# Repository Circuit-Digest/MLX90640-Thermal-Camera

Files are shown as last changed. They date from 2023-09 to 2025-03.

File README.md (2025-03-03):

# [MLX90640-Thermal-Camera](https://circuitdigest.com/microcontroller-projects/diy-thermal-camera-using-esp32-wrover-module-and-mlx90640-sensor) 

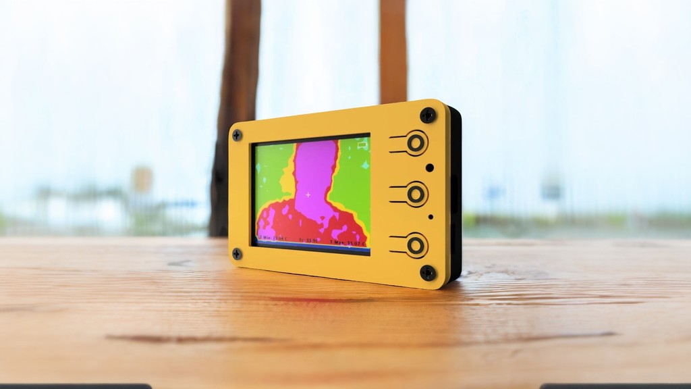
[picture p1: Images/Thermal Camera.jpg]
image_tooltip

<br>

<div style="display: flex; flex-wrap: nowrap;">
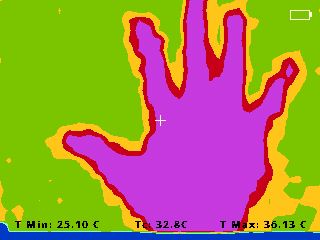
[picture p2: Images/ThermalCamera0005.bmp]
image_tooltip
    
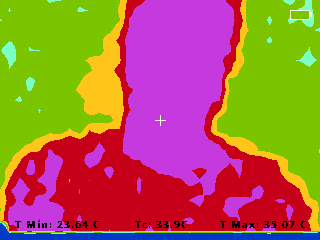
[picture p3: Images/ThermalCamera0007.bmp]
image_tooltip
    
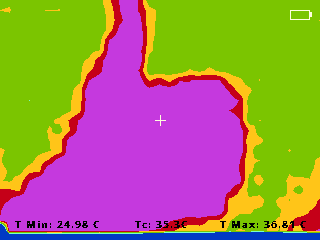
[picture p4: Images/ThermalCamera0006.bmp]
image_tooltip
    
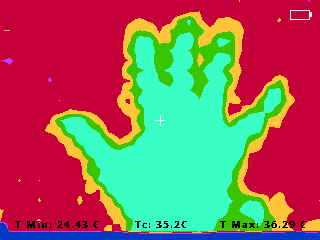
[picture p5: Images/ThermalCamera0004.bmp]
image_tooltip
    
</div>
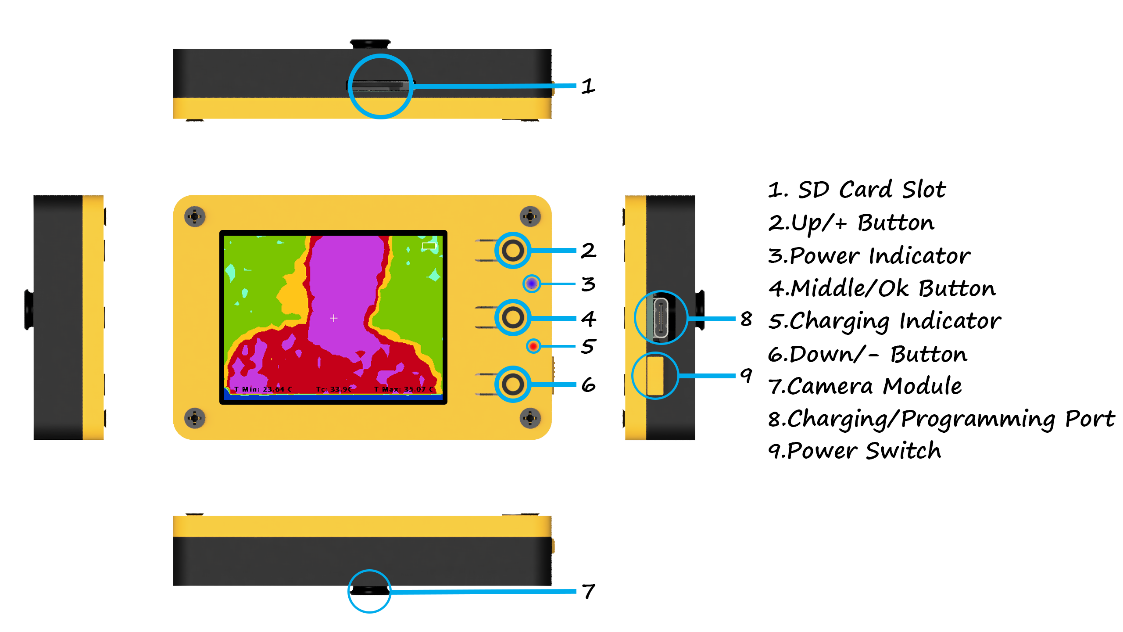
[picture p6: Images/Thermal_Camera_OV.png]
image_tooltip

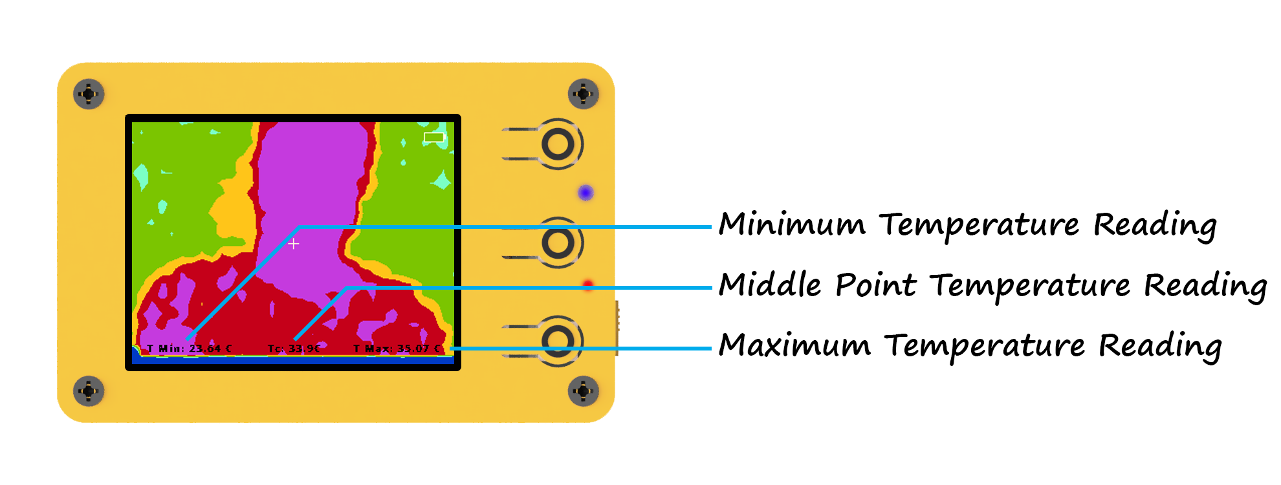
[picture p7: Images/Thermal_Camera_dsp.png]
image_tooltip
<br>
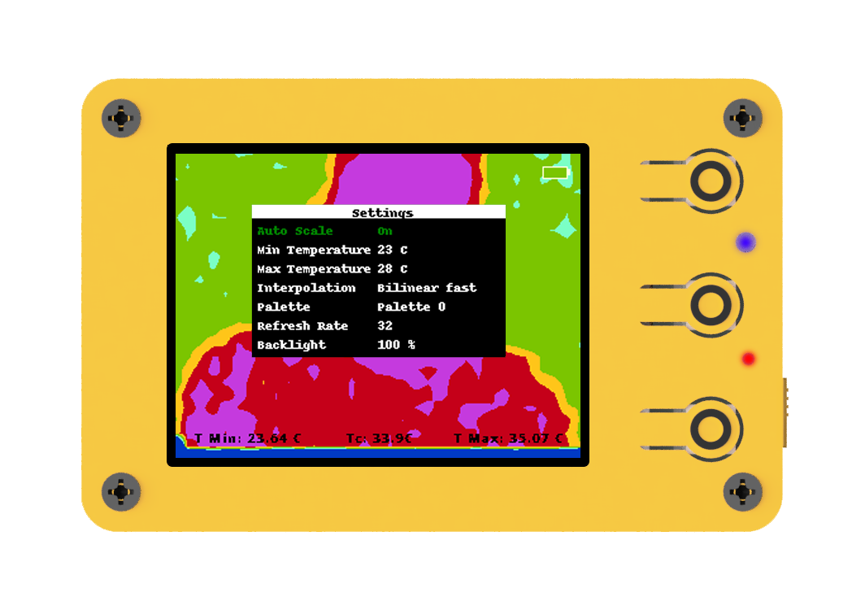
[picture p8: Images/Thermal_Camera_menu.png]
image_tooltip
<br>
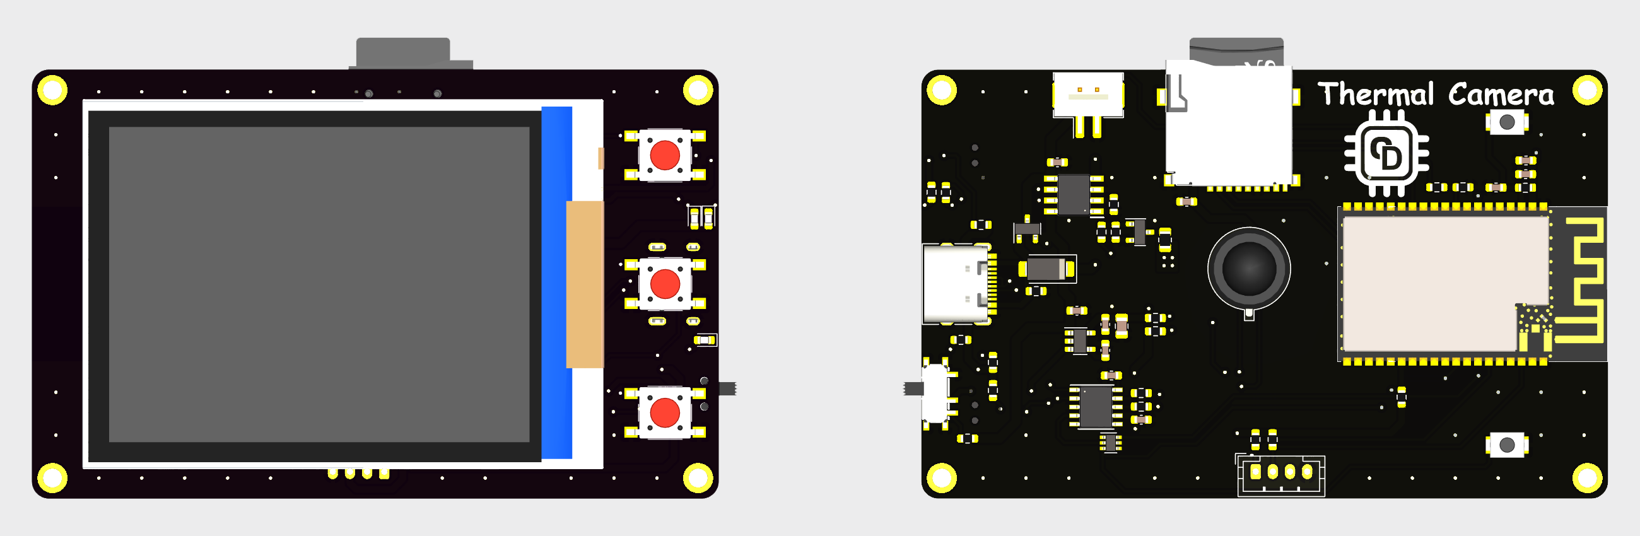
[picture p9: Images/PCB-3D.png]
image_tooltip
<br>
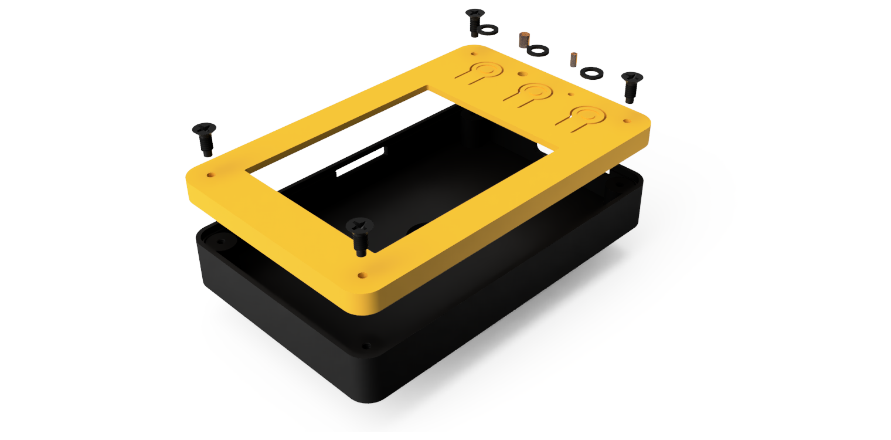
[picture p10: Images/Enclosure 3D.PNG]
image_tooltip
<br>
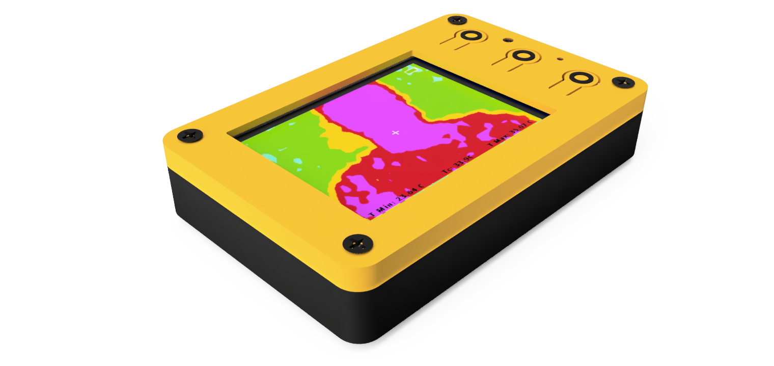
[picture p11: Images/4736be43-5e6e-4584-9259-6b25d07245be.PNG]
image_tooltip
<br>

<br>

Thermal Cameras are widely used in a wide range of industrial applications such as thermal performance monitoring, detecting temperature anomalies, thermal bench marking and many more. We even use thermal imaging even for defense and military applications. The most common application that we may come across, is might be the electronics repair industry. In repair industry the thermal cameras are a very important tool which can make the hardware debugging much easier especially where there are shorted parts are involved. The main concern regarding such thermal imager is that they are pretty expensive. 
So, in this project we are going to find some solution for that by making a DIY thermal imager using much cheaper available components. The cheaper thermal imaging sensors we have considered are the AMG8833 from Panasonic and MLX90640 and MLX90641 from Melexis. Even though the AMG8833 is the cheapest of them all it only has a resolution o f 8x8, while MLX90640 offers a resolution of 32x24 and MLX90641 offers a resolution of 16x12. Since the MLX90640 offers the best resolution in the price range we choose it for our DIY thermal camera.

<br>
[Note: As this projects are very simple we are only providing the code, schemaitic, and a few essential images if you want to get the images or code explanations do check out the Circuit Digest website.
<br>
<br>

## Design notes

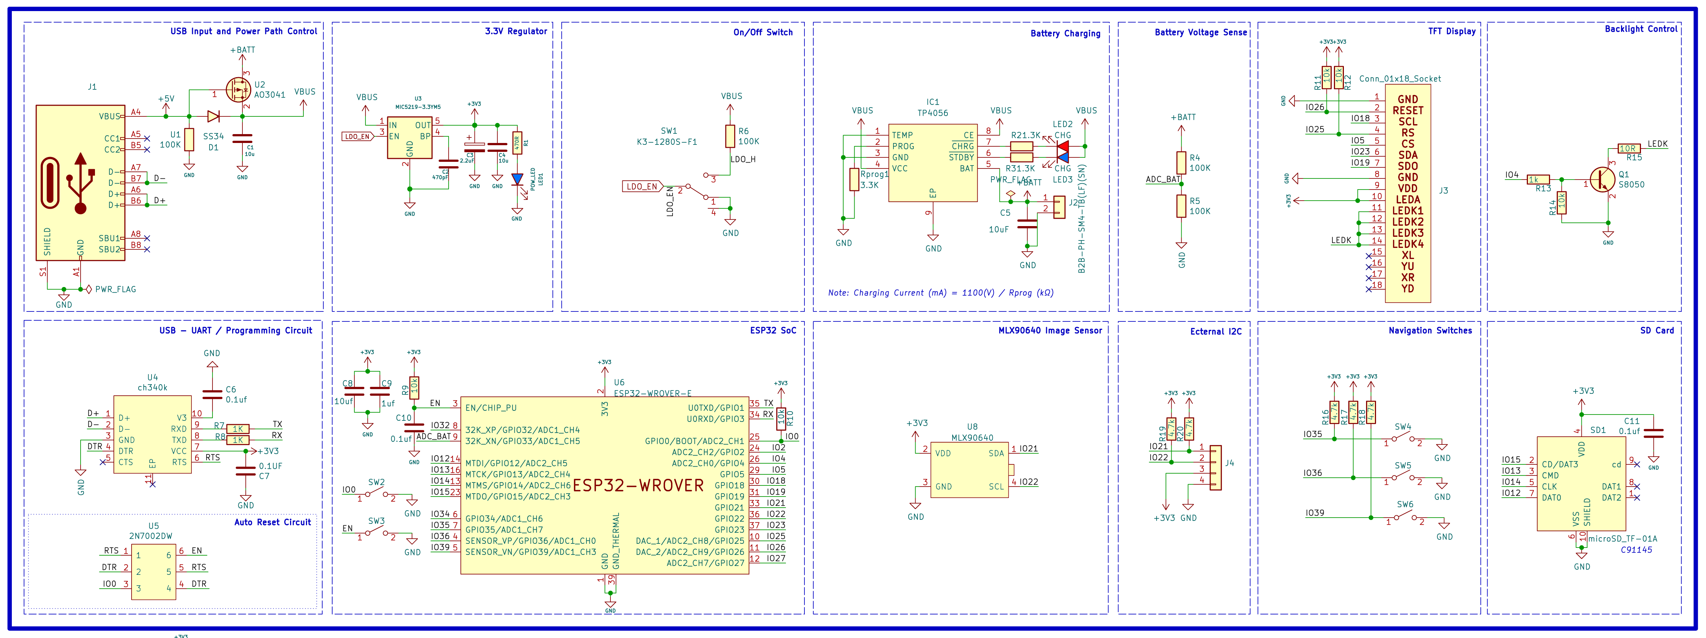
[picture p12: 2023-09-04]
Images/Thermal_Camera Schematics.png

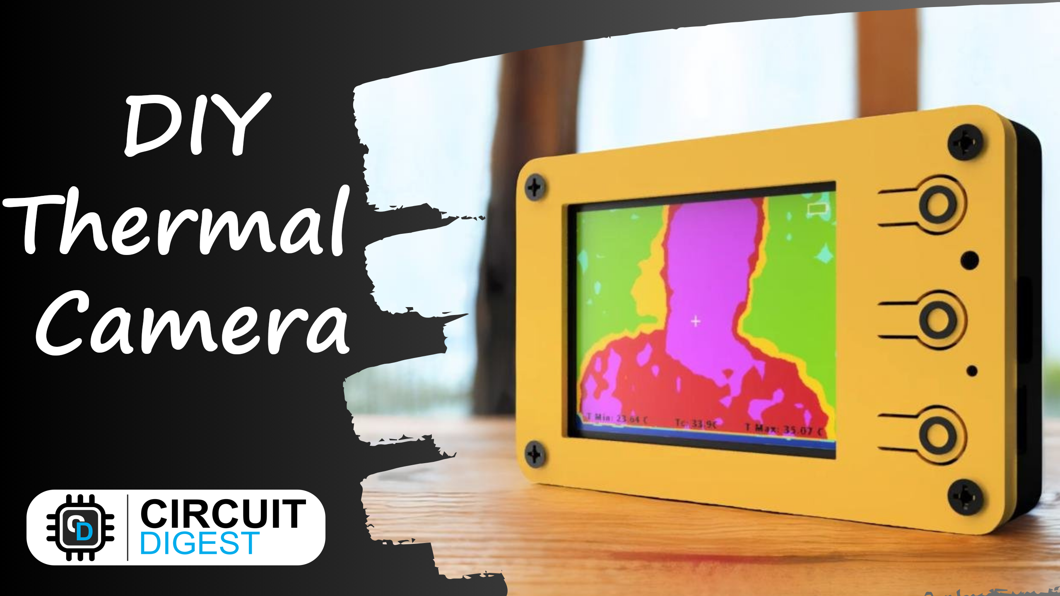
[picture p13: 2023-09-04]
Images/Title Image.png

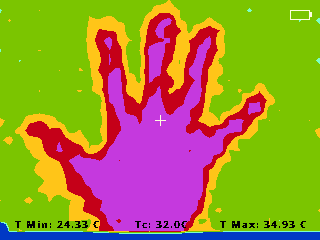
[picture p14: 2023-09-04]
Images/ThermalCamera0014.bmp

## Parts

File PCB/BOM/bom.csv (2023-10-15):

Designator | Footprint | Quantity | Value | LCSC Part #
C1, C4 | 603 | 2 | 10u
C10, C11, C6, C7 | 603 | 4 | 0.1uf
C2 | 603 | 1 | 470pF
C3 | 805 | 1 | 2.2uF
C5, C8 | 603 | 2 | 10uF
C9 | 603 | 1 | 1uf
D1 | D_SMA | 1 | SS34
H1, H2, H3, H4 | MountingHole_2.2mm_M2_ISO7380_Pad | 4 | MountingHole
IC1 | SOIC127P600X175-9N | 1 | TP4056
J1 | USB_C_Receptacle_HRO_TYPE-C-31-M-12 | 1 | USB_C_Receptacle_USB2.0
J2 | JST_PH_B2B-PH-SM4-TB_1x02-1MP_P2.00mm_Vertical | 1 | B2B-PH-SM4-TB(LF)(SN)
J3 | 24LCDILI9341 | 1 | Conn_01x18_Socket
J4 | JST_PH_B4B-PH-K_1x04_P2.00mm_Vertical | 1 | Stemma
LED1 | 603 | 1 | POW_LED
LED2, LED3 | 603 | 2 | CHG
Q1 | SOT-23 | 1 | S8050
R1 | 603 | 1 | 470R
R10, R11, R12, R14, R9 | 603 | 5 | 10k
R13, R7, R8 | 603 | 3 | 1k
R15 | 805 | 1 | 10R
R16, R17, R18, R19, R20 | 603 | 5 | 4.7k
R2, R3 | 603 | 2 | 1.3K
R4, R5, R6, U1 | 603 | 4 | 100K
Rprog1 | 603 | 1 | 3.3K
SD1 | microSD_TF-01A-C91145 | 1 | microSD_TF-01A
SW1 | slide switch spdt | 1 | K3-1280S-F1
SW2_4, SW2_3, SW2_2 | PTS645SL43SMTR92LFS | 3 | SW_SPST
SW2, SW3, SW4, SW5, SW6 | Tactile 3x4x2mm TS-A010 | 5 | TS-1088R-02526
U2 | SOT-23 | 1 | AO3401
U3 | SOT-23-5 | 1 | MIC5219-3.3YM5
U4 | ESSOP-10_3.9x4.9mm_P1.00mm | 1 | ch340k
U5 | SOT-363_SC-70-6 | 1 | 2N7002DW
U6 | ESP32-WROVER-E | 1 | ESP32-WROVER-E
U7 | ESP32-WROOM-32E | 1 | ESP32-WROOM-E
U8 | MLX90640 | 1 | MLX90640

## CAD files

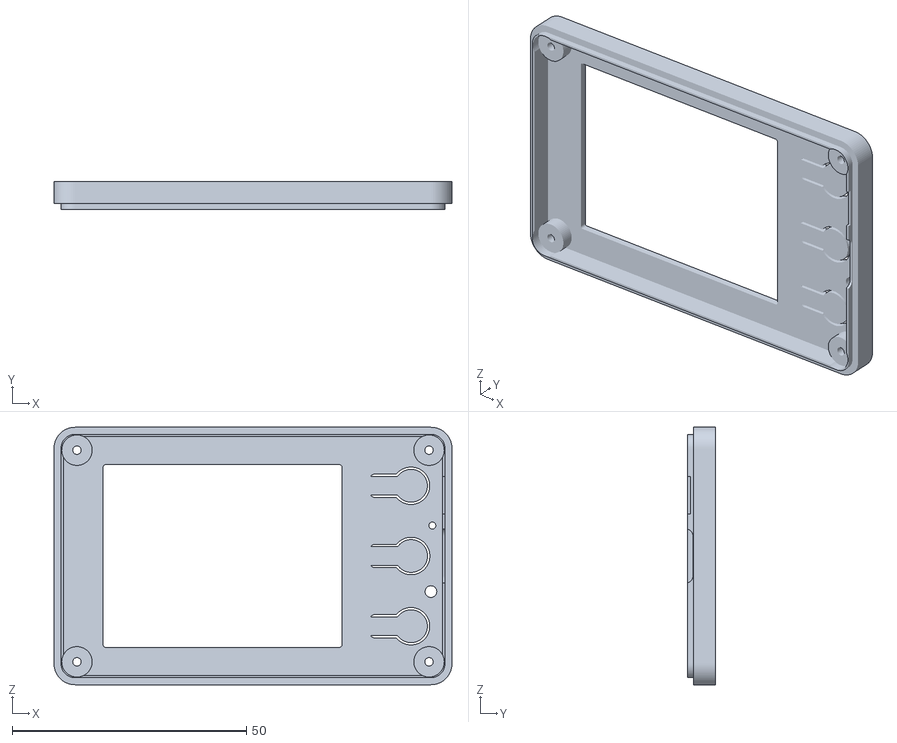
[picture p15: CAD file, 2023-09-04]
STL/top.stl
85.0 x 6.05 x 55.0

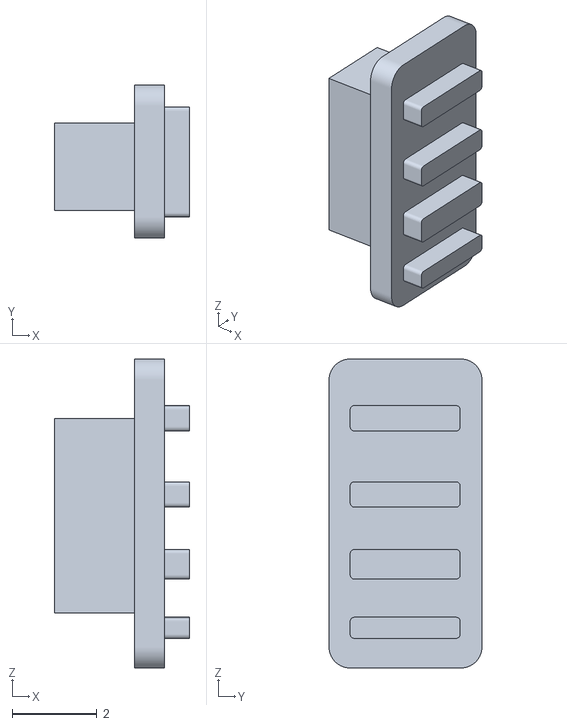
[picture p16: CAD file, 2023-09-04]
STL/slide.stl
3.20 x 3.61 x 7.30

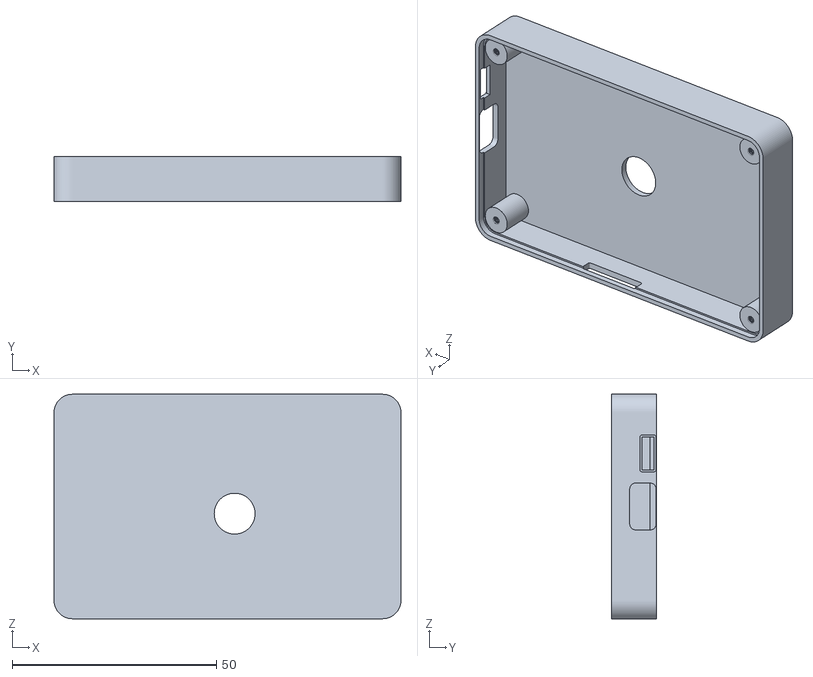
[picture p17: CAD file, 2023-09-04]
STL/Btm.stl
85.0 x 11.1 x 55.0

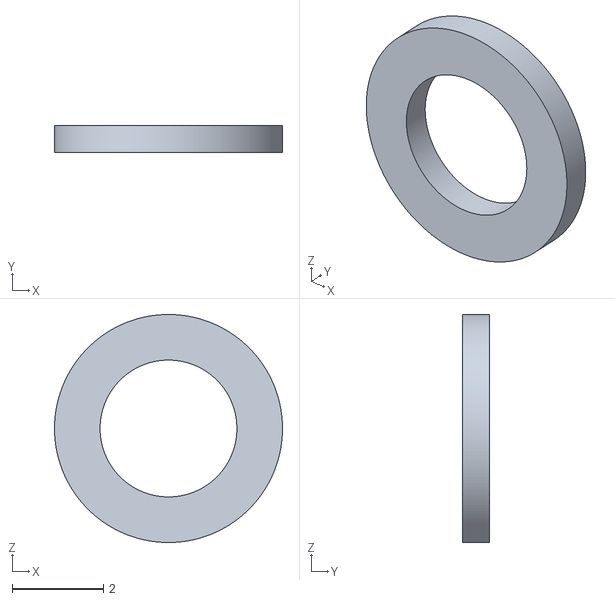
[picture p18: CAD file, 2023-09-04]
STL/button.stl
5.00 x 0.6 x 5.00

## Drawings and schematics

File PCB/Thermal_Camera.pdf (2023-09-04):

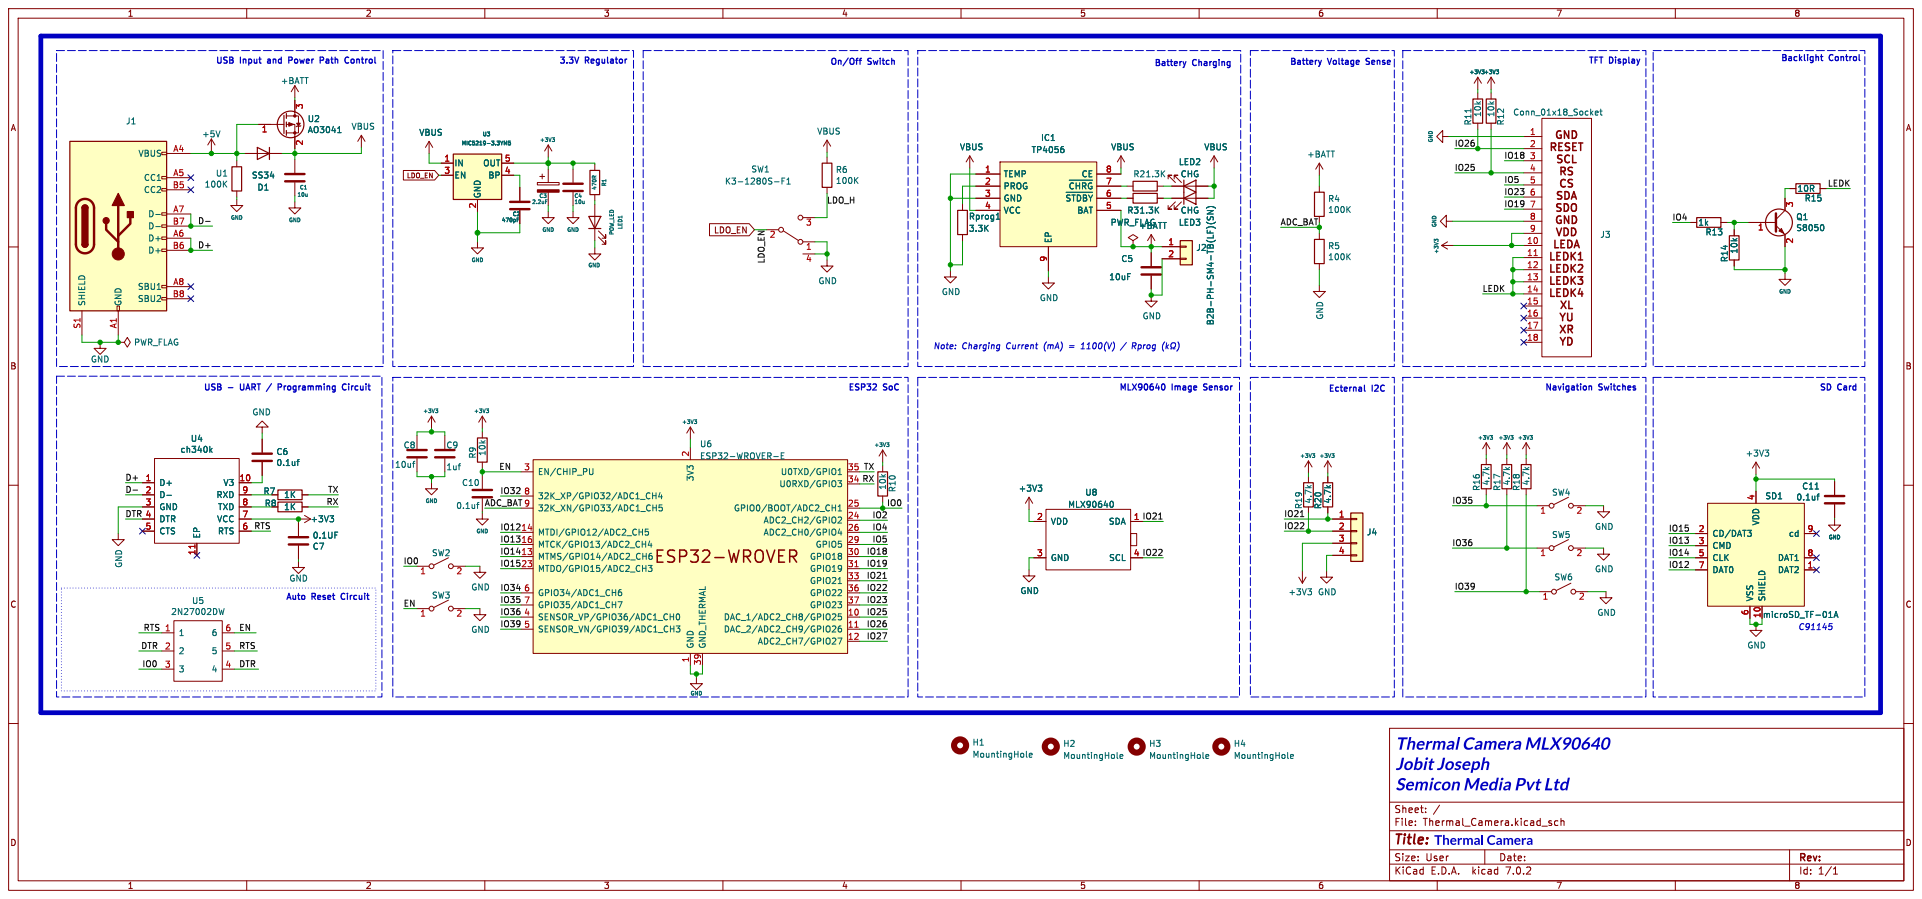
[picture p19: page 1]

TFT Display Note: Charging Current (mA) = 1100(V) / Rprog þÿ(k©)

2 3 U2AO3041 SDA 1 VDD 2 GND 3 SCL 4 U8 MLX90640 C6

LED3 CHG

Id: 1/1 Title: File: Thermal_Camera.kicad_sch Sheet: / +3V3

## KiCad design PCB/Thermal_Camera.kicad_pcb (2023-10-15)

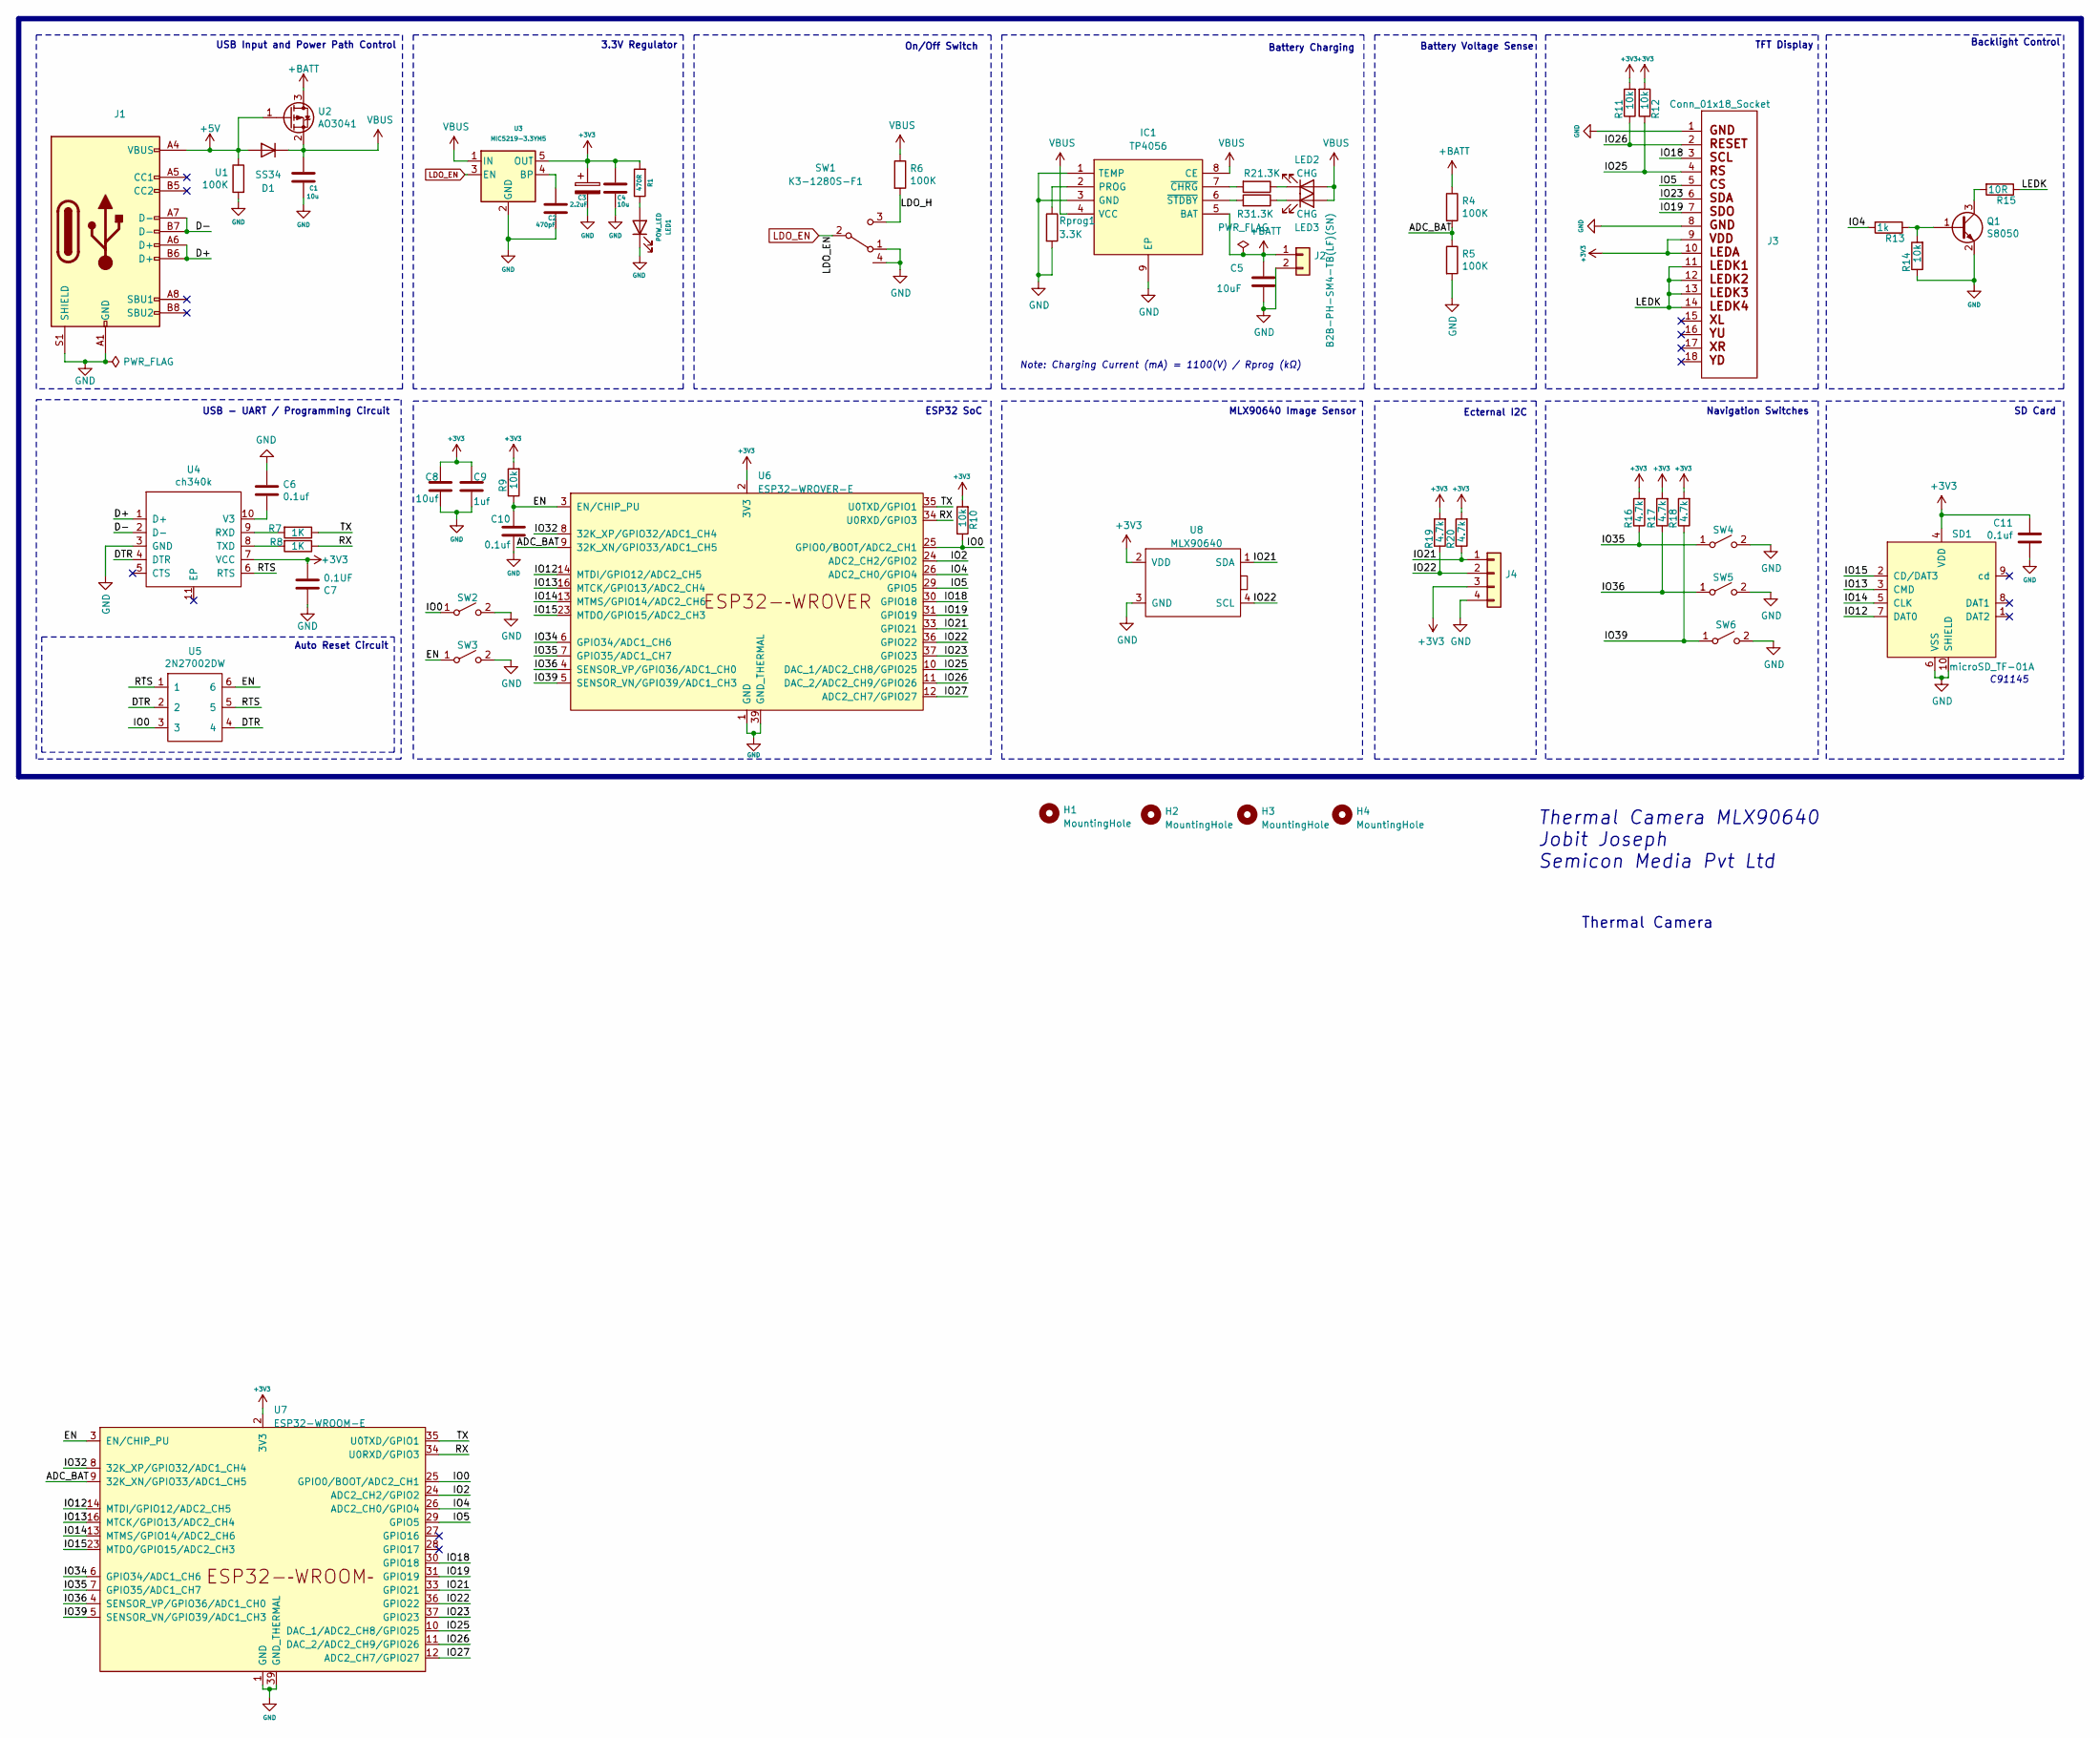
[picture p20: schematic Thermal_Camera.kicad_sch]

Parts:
C1, C4: 10u; C_0603_1608Metric
C2: 470pF; C_0603_1608Metric
C3: 2.2uF; C_0805_2012Metric
C5: 10uF; C_0603_1608Metric
C6, C10, C11: 0.1uf; C_0603_1608Metric
C7: 0.1UF; C_0603_1608Metric
C8: 10uf; C_0603_1608Metric
C9: 1uf; C_0603_1608Metric
D1: SS34; D_SMA
H1, H2, H3, H4: MountingHole; MountingHole_2.2mm_M2_ISO7380_Pad
IC1: TP4056; SOIC127P600X175-9N; Manufacturer_Part_Number TP4056-42-ESOP8
J1: USB_C_Receptacle_USB2.0; USB_C_Receptacle_HRO_TYPE-C-31-M-12
J2: B2B-PH-SM4-TB(LF)(SN); JST_PH_B2B-PH-SM4-TB_1x02-1MP_P2.00mm_Vertical
J3: Conn_01x18_Socket; 24LCDILI9341
J4: Stemma; JST_PH_B4B-PH-K_1x04_P2.00mm_Vertical
LED1: POW_LED; LED_0603_1608Metric
LED2, LED3: CHG; LED_0603_1608Metric
Q1: S8050; SOT-23
R1: 470R; R_0603_1608Metric
R2, R3: 1.3K; R_0603_1608Metric
R4, R5, R6: 100K; R_0603_1608Metric
R7, R8: 1K; R_0603_1608Metric
R9, R10, R11, R12, R14: 10k; R_0603_1608Metric
R13: 1k; R_0603_1608Metric
R15: 10R; R_0805_2012Metric
R16, R17, R18, R19, R20: 4.7k; R_0603_1608Metric
Rprog1: 3.3K; R_0603_1608Metric
SD1: microSD_TF-01A; microSD_TF-01A-C91145
SW1: K3-1280S-F1; slide switch spdt
SW2, SW3, SW4, SW5, SW6: TS-1088R-02526; Tactile 3x4x2mm TS-A010
U1: 100K; R_0603_1608Metric
U2: AO3041; SOT-23
U3: MIC5219-3.3YM5; SOT-23-5
U4: ch340k; ESSOP-10_3.9x4.9mm_P1.00mm
U5: 2N27002DW; SOT-363_SC-70-6
U6: ESP32-WROVER-E
U7: ESP32-WROOM-E; ESP32-WROOM-32E
U8: MLX90640

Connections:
+3V3: C3.1, C4.1, C7.2, C8.1, C9.1, C11.1, J3.9 (VDD), J3.10 (LEDA), J4.3, R1.2, R9.2, R10.2, R11.2, R12.2, R16.2, R17.2, R18.2, R19.2, R20.2, SD1.4 (VDD), U3.5 (OUT), U4.7 (VCC), U6.2 (3V3), U7.2 (3V3), U8.2 (VDD)
+5V: D1.2 (A), J1.A4 (VBUS), J1.A9 (VBUS), J1.B4 (VBUS), J1.B9 (VBUS), U1.1, U2.1 (G)
+BATT: C5.1, IC1.5 (BAT), J2.1, R4.1, U2.3 (D)
/ADC_BAT: R4.2, R5.1, U6.9 (32K_XN/GPIO33/ADC1_CH5), U7.9 (32K_XN/GPIO33/ADC1_CH5)
/D+: J1.A6 (D+), J1.B6 (D+), U4.1 (D+)
/D-: J1.A7 (D-), J1.B7 (D-), U4.2 (D-)
/DTR: U4.4 (DTR), U5.2, U5.4
/EN: C10.1, R9.1, SW3.1 (A), U5.6, U6.3 (EN/CHIP_PU), U7.3 (EN/CHIP_PU)
/IO2: U6.24 (ADC2_CH2/GPIO2), U7.24 (ADC2_CH2/GPIO2)
/IO4: R13.2, U6.26 (ADC2_CH0/GPIO4), U7.26 (ADC2_CH0/GPIO4)
/IO5: J3.5 (CS), U6.29 (GPIO5), U7.29 (GPIO5)
/IO12: SD1.7 (DAT0), U6.14 (MTDI/GPIO12/ADC2_CH5), U7.14 (MTDI/GPIO12/ADC2_CH5)
/IO13: SD1.3 (CMD), U6.16 (MTCK/GPIO13/ADC2_CH4), U7.16 (MTCK/GPIO13/ADC2_CH4)
/IO14: SD1.5 (CLK), U6.13 (MTMS/GPIO14/ADC2_CH6), U7.13 (MTMS/GPIO14/ADC2_CH6)
/IO15: SD1.2 (CD/DAT3), U6.23 (MTDO/GPIO15/ADC2_CH3), U7.23 (MTDO/GPIO15/ADC2_CH3)
/IO18: J3.3 (SCL), U6.30 (GPIO18), U7.30 (GPIO18)
/IO19: J3.7 (SDO), U6.31 (GPIO19), U7.31 (GPIO19)
/IO21: J4.1, R20.1, U6.33 (GPIO21), U7.33 (GPIO21), U8.1 (SDA)
/IO22: J4.2, R19.1, U6.36 (GPIO22), U7.36 (GPIO22), U8.4 (SCL)
/IO23: J3.6 (SDA), U6.37 (GPIO23), U7.37 (GPIO23)
/IO25: J3.4 (RS), R12.1, U6.10 (DAC_1/ADC2_CH8/GPIO25), U7.10 (DAC_1/ADC2_CH8/GPIO25)
/IO26: J3.2 (RESET), R11.1, U6.11 (DAC_2/ADC2_CH9/GPIO26), U7.11 (DAC_2/ADC2_CH9/GPIO26)
/IO27: U6.12 (ADC2_CH7/GPIO27), U7.12 (ADC2_CH7/GPIO27)
/IO32: U6.8 (32K_XP/GPIO32/ADC1_CH4), U7.8 (32K_XP/GPIO32/ADC1_CH4)
/IO34: U6.6 (GPIO34/ADC1_CH6), U7.6 (GPIO34/ADC1_CH6)
/IO36: R17.1, SW5.1 (A), U6.4 (SENSOR_VP/GPIO36/ADC1_CH0), U7.4 (SENSOR_VP/GPIO36/ADC1_CH0); also elsewhere on the board
/IO39: R18.1, SW6.1 (A), U6.5 (SENSOR_VN/GPIO39/ADC1_CH3), U7.5 (SENSOR_VN/GPIO39/ADC1_CH3); also elsewhere on the board
/LDO_H: R6.2, SW1.3 (C)
/LEDK: J3.11 (LEDK1), J3.12 (LEDK2), J3.13 (LEDK3), J3.14 (LEDK4), R15.1
/RTS: U4.6 (RTS), U5.1, U5.5
/RX: R8.1, U6.34 (U0RXD/GPIO3), U7.34 (U0RXD/GPIO3)
/TX: R7.1, U6.35 (U0TXD/GPIO1), U7.35 (U0TXD/GPIO1)
LDO_EN: SW1.2 (B), U3.3 (EN)
unnamed: IC1.2 (PROG), Rprog1.1
unnamed: IC1.7 (~CHRG), R2.2
unnamed: IC1.6 (~STDBY), R3.2
unnamed: LED1.2 (A), R1.1
unnamed: LED2.1 (K), R2.1
unnamed: LED3.1 (K), R3.1
unnamed: Q1.3 (C), R15.2
unnamed: Q1.1 (E), R13.1, R14.2
unnamed: C2.1, U3.4 (BP)
unnamed: R7.2, U4.9 (RXD)
unnamed: R8.2, U4.8 (TXD)
unnamed: C6.2, U4.10 (V3)
VBUS: C1.1, D1.1 (K), IC1.4 (VCC), IC1.8 (CE), LED2.2 (A), LED3.2 (A), R6.1, U2.2 (S), U3.1 (IN)

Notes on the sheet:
Auto Reset Circuit
Battery Charging
Navigation Switches
Thermal Camera MLX90640 Jobit Joseph Semicon Media Pvt Ltd
TFT Display
MLX90640 Image Sensor
On/Off Switch
Ecternal I2C
Note: Charging Current (mA) = 1100(V) / Rprog (kΩ)
ESP32 SoC
C91145
Backlight Control
SD Card
3.3V Regulator
Battery Voltage Sense
USB Input and Power Path Control
Thermal Camera
USB - UART / Programming Circuit

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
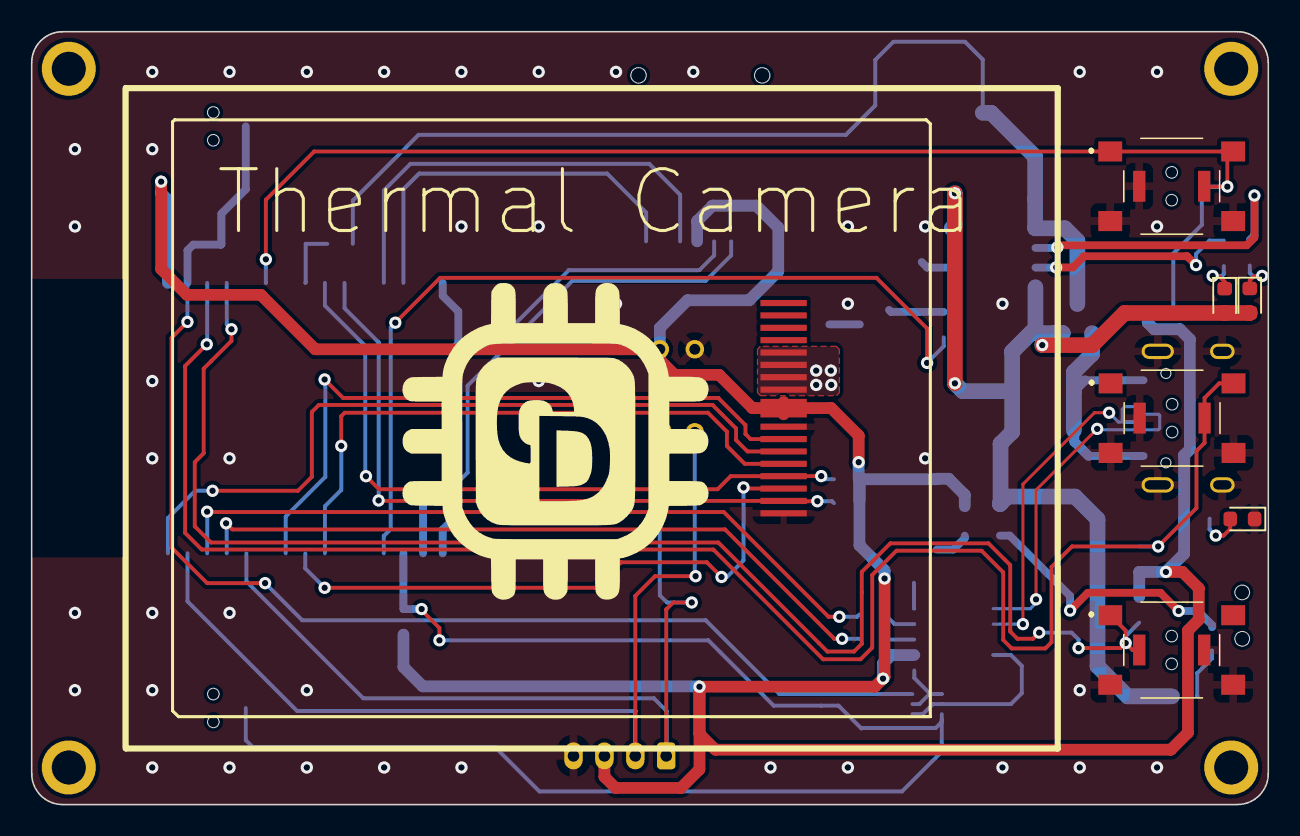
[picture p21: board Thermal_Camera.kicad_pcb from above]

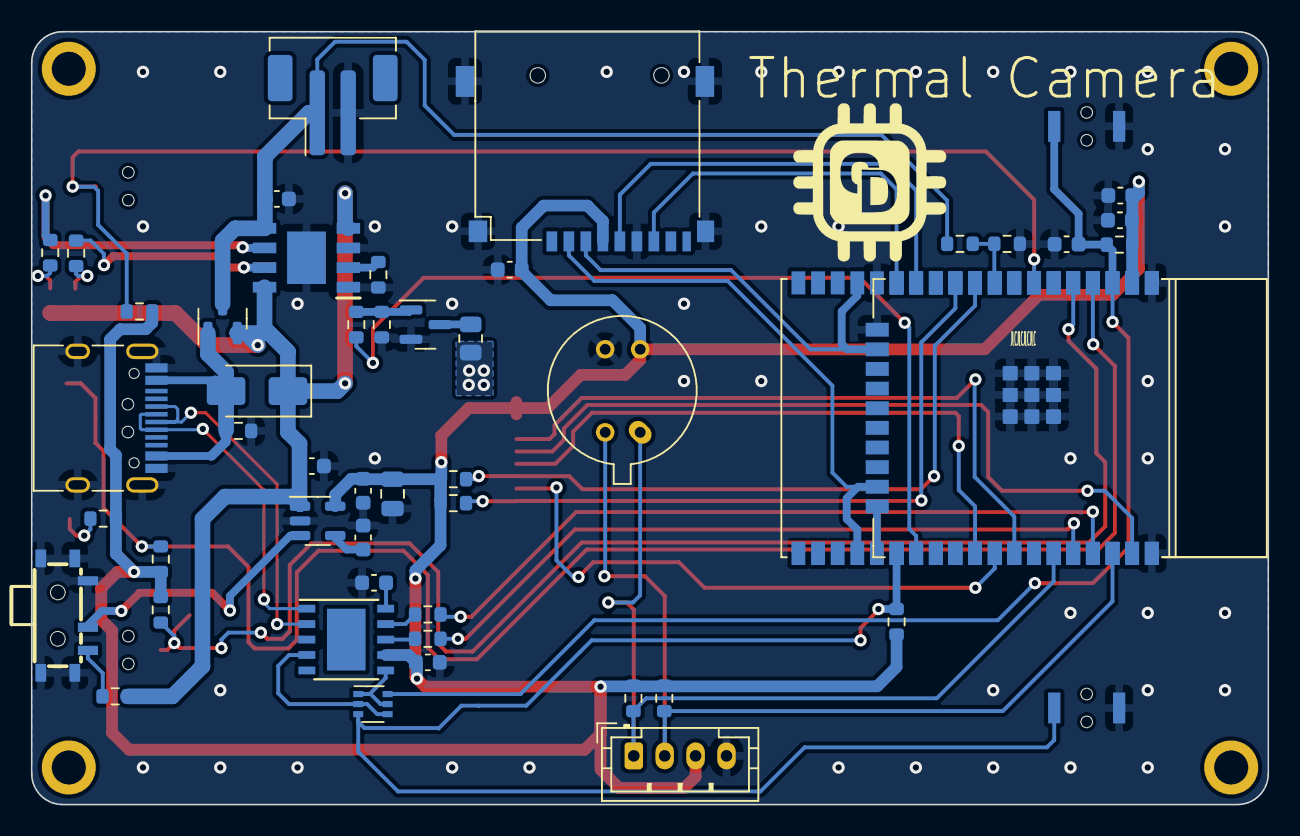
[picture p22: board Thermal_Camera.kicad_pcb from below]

Board: 2 copper layers, 80.0 x 50.0 mm, 64 parts (50 on the bottom side), 49 nets.

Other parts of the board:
SW2#2, SW2#3: SW_SPST; PTS645SL43SMTR92LFS
SW2#4: TS-1088R-02526; Tactile 3x4x2mm TS-A010

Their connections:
/IO36: SW2#2.2 (A); also elsewhere on the board
/IO39: SW2#3.1 (A); also elsewhere on the board

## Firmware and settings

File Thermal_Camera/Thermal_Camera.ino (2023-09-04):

/*
 * Project Name: MLX90640 Thermal Camera
 * Project Brief: Firmware for Thermal camera built around ESP32 and MLX90640
 * Author: Jobit Joseph
 * Copyright © Jobit Joseph
 * Copyright © Semicon Media Pvt Ltd
 * Copyright © Circuitdigest.com
 * 
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
 */
#include <Preferences.h>
#include <Wire.h>
#include <SPI.h>
#include <SD.h>
#include "FS.h"
#include <Adafruit_MLX90640.h>
#include <TFT_eSPI.h>
#include <AnimatedGIF.h>
#include <Fonts/GFXFF/gfxfont.h>  //Include a library of Fonts
#include "Open_Sans_ExtraBold_10.h"
#include "BootAnimation.h"
#include "success.h"
#include "Error.h"
SPIClass spiSD(HSPI);
#define SD_CS 15
//#define USE_DMA
#define NORMAL_SPEED
#define TFT_WIDTH 320
#define TFT_HEIGHT 240
#define BUFFER_SIZE 320
uint16_t usTemp[BUFFER_SIZE];
#define VBAT_PIN 33
#define BATTV_MAX 4.2  // maximum voltage of battery
#define BATTV_MIN 3.2  // what we regard as an empty battery
#define GIF_IMAGE BootAnimationIMG
#define SGIF_IMAGE success_GIF
#define EGIF_IMAGE Error_GIF
bool dmaBuf = 0;
Adafruit_MLX90640 mlx;
Preferences preferences;
AnimatedGIF gif;
TFT_eSPI tft = TFT_eSPI();
File bmpFile;
float frame[32 * 24];
float batv;
const int upButton = 35;
const int middleButton = 36;
const int downButton = 39;
const int backlightPin = 4;
int interpolationMode = 0;
int AutoScale = 0;
volatile bool MenuChange = false;
volatile bool _upShort = false;
volatile bool _downShort = false;
volatile bool middleShort = false;
volatile bool middlePressed = false;
unsigned long middlePressStartTime = 0;
int Menu = 0, Menuitem = 0;
int BLPWM = 0;
int RefreshRate = 0;
float MinT, MaxT;
String menuItems[7] = { "Auto Scale    : ", "Min Temp      : ", "Max Temp      : ", "Interpolation : ", "Palette       : ", "Refresh Rate  : ", "BackLight     : " };
String ASindex[2] = { "Off", "On" };
String IPindex[6] = { "Nearest Neighbor", "Average", "Bilinear", "Bilinear Fast", "Triangle" };
String RRindex[4] = { "4 Hz", "8 Hz", "16 Hz", "32 Hz" };
float xRatios[320];
float yRatios[240];
float xOppositeRatios[320];
float yOppositeRatios[240];
#define PALETTE_COUNT 10
uint16_t colorPalettes[PALETTE_COUNT][6] = {
  { TFT_BLUE, TFT_CYAN, TFT_GREEN, TFT_YELLOW, TFT_RED, TFT_MAGENTA },
  { TFT_BLACK, TFT_DARKGREY, TFT_LIGHTGREY, TFT_WHITE, TFT_ORANGE, TFT_PINK },
  { TFT_NAVY, TFT_OLIVE, TFT_DARKGREEN, TFT_DARKCYAN, TFT_MAROON, TFT_PURPLE },
  { TFT_BLUE, TFT_GREEN, TFT_DARKGREEN, TFT_ORANGE, TFT_MAROON, TFT_RED },
  { TFT_NAVY, TFT_DARKGREEN, TFT_GREEN, TFT_YELLOW, TFT_ORANGE, TFT_RED },
  { TFT_CYAN, TFT_BLUE, TFT_MAGENTA, TFT_YELLOW, TFT_GREEN, TFT_RED },
  { TFT_WHITE, TFT_ORANGE, TFT_RED, TFT_BLUE, TFT_GREEN, TFT_BLACK },
  { TFT_PURPLE, TFT_MAGENTA, TFT_RED, TFT_ORANGE, TFT_YELLOW, TFT_GREEN },
  { TFT_YELLOW, TFT_PINK, TFT_WHITE, TFT_BLUE, TFT_DARKCYAN, TFT_DARKGREEN },
  { TFT_RED, TFT_YELLOW, TFT_GREEN, TFT_CYAN, TFT_BLUE, TFT_MAGENTA }
};
int paletteIndex = 0;

float tempMin = 20.0;  // Minimum temperature
float tempMax = 32.0;  // Maximum temperature

TFT_eSprite sprite = TFT_eSprite(&tft);


void IRAM_ATTR upButton_ISR() {
  static unsigned long last_interrupt_time = 0;
  unsigned long interrupt_time = millis();

  if (interrupt_time - last_interrupt_time > 200) {  // simple debounce
    _upShort = true;
  }
  last_interrupt_time = interrupt_time;
}

void IRAM_ATTR downButton_ISR() {
  static unsigned long last_interrupt_time = 0;
  unsigned long interrupt_time = millis();

  if (interrupt_time - last_interrupt_time > 200) {  // simple debounce
    _downShort = true;
  }
  last_interrupt_time = interrupt_time;
}

void IRAM_ATTR middleButton_ISR() {
  if (digitalRead(middleButton) == LOW) {
    // Button press event
    if (!middlePressed) {  // If button was not already being pressed
      middlePressed = true;
      middlePressStartTime = millis();  // Save the start time of button press
    }
  } else {
    // Button release event
    if (middlePressed) {                             // If the button was being pressed
      if (millis() - middlePressStartTime < 1000) {  // If the button was pressed for less than 1 second
        middleShort = true;
      }
      middlePressed = false;
      middlePressStartTime = 0;  // Reset the start time of button press
    }
  }
}



void MLXInit() {

  Wire.begin();
  Wire.setClock(1000000);
  if (!mlx.begin()) {
    Serial.println("Failed to initialize MLX90640!");
  }
  mlx.setResolution(MLX90640_ADC_18BIT);
  ConfigRefreshrate();
}
void ConfigRefreshrate() {
  switch (RefreshRate) {
    case 1:
      mlx.setRefreshRate(MLX90640_4_HZ);
      break;
    case 2:
      mlx.setRefreshRate(MLX90640_8_HZ);
      break;
    case 3:
      mlx.setRefreshRate(MLX90640_16_HZ);
      break;
    case 4:
      mlx.setRefreshRate(MLX90640_32_HZ);
      break;
    default:
      break;
  }
}
void ReadConfig() {
  preferences.begin("Config", false);
  String temp;
  temp = preferences.getString("AutoScale", "");
  AutoScale = temp.toInt();
  temp = preferences.getString("MinTe", "");
  MinT = temp.toFloat();
  temp = preferences.getString("MaxTe", "");
  MaxT = temp.toFloat();
  temp = preferences.getString("Imode", "");
  interpolationMode = temp.toInt();
  temp = preferences.getString("PIndex", "");
  paletteIndex = temp.toInt();
  temp = preferences.getString("RefreshRate", "");
  RefreshRate = temp.toInt();
  temp = preferences.getString("BLPWM", "");
  BLPWM = temp.toInt();
  preferences.end();
}
void WriteConfig() {
  preferences.begin("Config", false);
  preferences.putString("AutoScale", String(AutoScale));
  preferences.putString("MinTe", String(MinT));
  preferences.putString("MaxTe", String(MaxT));
  preferences.putString("Imode", String(interpolationMode));
  preferences.putString("PIndex", String(paletteIndex));
  preferences.putString("RefreshRate", String(RefreshRate));
  preferences.putString("BLPWM", String(BLPWM));
  preferences.end();
}

void initSDcard() {
  //spiSD.begin(14, 12, 13, SD_CS);  //CLK,MISO,MOIS,SS
  if (!SD.begin(SD_CS, spiSD)) {
    Serial.println("Card Mount Failed");
    return;
  } else {
    Serial.println("Card Mount Successful");
  }
  uint8_t cardType = SD.cardType();

  if (cardType == CARD_NONE) {
    Serial.println("No SD card attached");
    return;
  }
}
String generateFilename(fs::FS &fs) {
  for (int i = 0; i <= 9999; i++) {
    char filename[23];                               // Allocate the char array
    sprintf(filename, "/ThermalCamera%04d.bmp", i);  // Print formatted string into char array

    if (!fs.exists(filename)) {
      return String(filename);  // Return a String object
    }
  }

  return "";  // return empty string if all filenames are taken
}
int writeBMP(fs::FS &fs, const char *path, TFT_eSprite *sprite) {
  const int width = sprite->width();
  const int height = sprite->height();

  // BMP file header (14 bytes)
  uint8_t bmpFileHeader[14] = { 'B', 'M', 0, 0, 0, 0, 0, 0, 0, 0, 54, 0, 0, 0 };

  // The size of the BMP file in bytes
  uint32_t fileSize = 54 + width * height * 2;
  bmpFileHeader[2] = (uint8_t)(fileSize);
  bmpFileHeader[3] = (uint8_t)(fileSize >> 8);
  bmpFileHeader[4] = (uint8_t)(fileSize >> 16);
  bmpFileHeader[5] = (uint8_t)(fileSize >> 24);

  // BMP info header (40 bytes)
  uint8_t bmpInfoHeader[40] = { 40, 0, 0, 0, 0, 0, 0, 0, 0, 0, 0, 0, 1, 0, 16, 0 };

  bmpInfoHeader[4] = (uint8_t)(width);
  bmpInfoHeader[5] = (uint8_t)(width >> 8);
  bmpInfoHeader[6] = (uint8_t)(width >> 16);
  bmpInfoHeader[7] = (uint8_t)(width >> 24);

  bmpInfoHeader[8] = (uint8_t)(height);
  bmpInfoHeader[9] = (uint8_t)(height >> 8);
  bmpInfoHeader[10] = (uint8_t)(height >> 16);
  bmpInfoHeader[11] = (uint8_t)(height >> 24);

  File file = fs.open(path, FILE_WRITE);
  if (!file) {
    Serial.println("Failed to open file for writing");
    return 0;
  } else {

    //showSavingImageMessage();
    // Write headers
    file.write(bmpFileHeader, 14);
    file.write(bmpInfoHeader, 40);

    // Write pixel data
    for (int y = height - 1; y >= 0; y--) {  // BMP is stored bottom-top
      for (int x = 0; x < width; x++) {
        uint16_t pixel = sprite->readPixel(x, y);
        // Swap red and green channels
        uint16_t r = (pixel >> 11) & 0x1F;
        uint16_t g = (pixel >> 5) & 0x3F;
        uint16_t b = pixel & 0x1F;
        pixel = (b << 11) | (r << 5) | g;
        file.write(pixel >> 8);  // high byte
        file.write(pixel);       // low byte
      }
    }
    file.close();
    return 1;
  }
}


void navigationUpdate() {
  if (_upShort == true) {
    _upShort = false;
    if (Menu == 0) {
      interpolationMode++;
      if (interpolationMode > 4) interpolationMode = 0;
    } else {
      if (Menuitem == 0) {
        AutoScale++;
        if (AutoScale > 1) AutoScale = 1;
      } else if (Menuitem == 1) {
        MinT++;
        if (MinT > 300) MinT = 300;
      } else if (Menuitem == 2) {
        MaxT++;
        if (MaxT > 300) MaxT = 300;
      } else if (Menuitem == 3) {
        interpolationMode++;
        if (interpolationMode > 4) interpolationMode = 4;
      } else if (Menuitem == 4) {
        paletteIndex++;
        if (paletteIndex > 9) paletteIndex = 9;
      } else if (Menuitem == 5) {
        RefreshRate++;
        if (RefreshRate > 3) RefreshRate = 3;
        ConfigRefreshrate();
      } else if (Menuitem == 6) {
        BLPWM = BLPWM + 10;
        if (BLPWM > 100) BLPWM = 100;
        analogWrite(backlightPin, map(BLPWM, 0, 100, 0, 255));  // Turn on backlight
      }
      MenuChange = true;
    }
    WriteConfig();
    Serial.println("Up Short Press");
  }
  if (_downShort == true) {
    _downShort = false;
    if (Menu == 0) {
      paletteIndex = (paletteIndex + 1) % PALETTE_COUNT;
    } else {
      if (Menuitem == 0) {
        AutoScale--;
        if (AutoScale < 0) AutoScale = 0;
      } else if (Menuitem == 1) {
        MinT--;
        if (MinT < 0) MinT = 0;
      } else if (Menuitem == 2) {
        MaxT--;
        if (MaxT < 5) MaxT = 5;
      } else if (Menuitem == 3) {
        interpolationMode--;
        if (interpolationMode < 0) interpolationMode = 0;
      } else if (Menuitem == 4) {
        paletteIndex--;
        if (paletteIndex < 0) paletteIndex = 0;
      } else if (Menuitem == 5) {
        RefreshRate--;
        if (RefreshRate < 0) RefreshRate = 0;
        ConfigRefreshrate();
      } else if (Menuitem == 6) {
        BLPWM = BLPWM - 10;
        if (BLPWM < 10) BLPWM = 10;
        analogWrite(backlightPin, map(BLPWM, 0, 100, 0, 255));  // Turn on backlight
      }
      MenuChange = true;
    }
    WriteConfig();
    Serial.println("down Short Press");
  }
  if (middleShort == true) {
    middleShort = false;
    if (Menu == 0) {
      if (!SD.begin(SD_CS, spiSD)) {
        Serial.println("Card Mount Failed");
        if (gif.open((uint8_t *)EGIF_IMAGE, sizeof(EGIF_IMAGE), GIFDraw1)) {
          Serial.printf("Successfully opened GIF; Canvas size = %d x %d\n", gif.getCanvasWidth(), gif.getCanvasHeight());
          while (gif.playFrame(true, NULL)) {
            sprite.pushSprite(0, 0);  // Push the sprite to screen after every frame
            yield();
          }
          gif.close();
        }
        return;
      } else {
        Serial.println("Card Mount Successful");
      }
      uint8_t cardType = SD.cardType();

      if (cardType == CARD_NONE) {
        Serial.println("No SD card attached");

        if (gif.open((uint8_t *)EGIF_IMAGE, sizeof(EGIF_IMAGE), GIFDraw1)) {
          Serial.printf("Successfully opened GIF; Canvas size = %d x %d\n", gif.getCanvasWidth(), gif.getCanvasHeight());
          while (gif.playFrame(true, NULL)) {
            sprite.pushSprite(0, 0);  // Push the sprite to screen after every frame
            yield();
          }
          gif.close();
        }
        return;
      } else {
        String filename = generateFilename(SD);
        if (filename != "") {
          if (writeBMP(SD, filename.c_str(), &sprite)) {

            if (gif.open((uint8_t *)SGIF_IMAGE, sizeof(SGIF_IMAGE), GIFDraw1)) {
              Serial.printf("Successfully opened GIF; Canvas size = %d x %d\n", gif.getCanvasWidth(), gif.getCanvasHeight());
              while (gif.playFrame(true, NULL)) {
                sprite.pushSprite(0, 0);  // Push the sprite to screen after every frame
                yield();
              }
              gif.close();
            }
          } else {

            if (gif.open((uint8_t *)EGIF_IMAGE, sizeof(EGIF_IMAGE), GIFDraw1)) {
              Serial.printf("Successfully opened GIF; Canvas size = %d x %d\n", gif.getCanvasWidth(), gif.getCanvasHeight());
              while (gif.playFrame(true, NULL)) {
                sprite.pushSprite(0, 0);  // Push the sprite to screen after every frame
                yield();
              }
              gif.close();
            }
          }
        } else {
          Serial.println("Failed to create filename.");

          if (gif.open((uint8_t *)EGIF_IMAGE, sizeof(EGIF_IMAGE), GIFDraw1)) {
            Serial.printf("Successfully opened GIF; Canvas size = %d x %d\n", gif.getCanvasWidth(), gif.getCanvasHeight());
            while (gif.playFrame(true, NULL)) {
              sprite.pushSprite(0, 0);  // Push the sprite to screen after every frame
              yield();
            }
            gif.close();
          }
        }
      }
    } else {
      Menuitem++;
      if (Menuitem > 6) {
        Menuitem = 0;
      }
      MenuChange = true;
    }
    Serial.println("Middle Short Press");
    Serial.print(Menu);
    Serial.print("");
    Serial.println(Menuitem);
  }
  if (middlePressed && !middleShort && millis() - middlePressStartTime > 1000 && middlePressed && !middleShort && millis() - middlePressStartTime < 1500) {
    // If the button is being pressed, no short press has been registered, and it has been over 1 second
    Serial.println("Middle Long Press");
    middlePressed = false;     // Reset the pressed flag
    middlePressStartTime = 0;  // Reset the press start time
    if (Menu == 0) {
      Menu = 1;
      MenuChange = true;
      Menuitem = 0;
    } else {
      Menu = 0;
    }
  }
}

void displayUpdate() {

  if (!mlx.getFrame(frame)) {
    // Failed to get frame, so reinitialize
    MLXInit();
  }

  float tempMinRead = 1000;   // some high value
  float tempMaxRead = -1000;  // some low value
  float tempCenter = 0.0;     // Temperature at center

  // Update the minimum and maximum temperatures read from the sensor
  for (int i = 0; i < 32 * 24; i++) {
    if (frame[i] < tempMinRead) {
      tempMinRead = frame[i];
    }
    if (frame[i] > tempMaxRead) {
      tempMaxRead = frame[i];
    }
    // Get the temperature at center
    if (i == 32 * 12 + 16) {
      tempCenter = frame[i];
    }
  }


  sprite.fillSprite(TFT_BLACK);

  if (interpolationMode == 0) {
    // Nearest neighbor interpolation
    for (int y = 0; y < 240; y++) {
      int yIndex = (y / 10) * 32;
      for (int x = 0; x < 320; x++) {
        float val = frame[yIndex + (x / 10)];
        drawPixel(319 - x, y, val);
      }
    }
  } else if (interpolationMode == 1) {
    // Average Interpolation
    for (int y = 0; y < 240; y++) {
      int yIndex = (y / 10) * 32;
      int yNextIndex = ((y / 10) + 1) * 32;  // Next row in original data
      for (int x = 0; x < 320; x++) {
        int xIndex = x / 10;

        // Take average of current and next points in x and y
        float val = (frame[yIndex + xIndex] + frame[yIndex + xIndex + 1] + frame[yNextIndex + xIndex] + frame[yNextIndex + xIndex + 1]) / 4.0;

        drawPixel(319 - x, y, val);
      }
    }
  } else if (interpolationMode == 2) {
    // Bilinear interpolation
    for (int y = 0; y < 240; y++) {
      int yIndex = (y / 10) * 32;
      float y_ratio = (y % 10) / 10.0;
      float y_opposite_ratio = 1 - y_ratio;
      for (int x = 0; x < 320; x++) {
        float x_ratio = (x % 10) / 10.0;
        float x_opposite_ratio = 1 - x_ratio;
        int x_over_10 = x / 10;
        float val = y_opposite_ratio * (x_opposite_ratio * frame[yIndex + x_over_10] + x_ratio * frame[yIndex + x_over_10 + 1]) + y_ratio * (x_opposite_ratio * frame[(yIndex + 32) + x_over_10] + x_ratio * frame[(yIndex + 32) + x_over_10 + 1]);
        drawPixel(319 - x, y, val);
      }
    }
  } else if (interpolationMode == 3) {
    // Bilinear interpolation
    int yIndex;
    int xIndex;
    int yNextIndex;

    for (int y = 0; y < 240; y++) {
      yIndex = (y / 10) * 32;
      yNextIndex = yIndex + 32;
      for (int x = 0; x < 320; x++) {
        xIndex = x / 10;
        float val = yOppositeRatios[y] * (xOppositeRatios[x] * frame[yIndex + xIndex] + xRatios[x] * frame[yIndex + xIndex + 1]) + yRatios[y] * (xOppositeRatios[x] * frame[yNextIndex + xIndex] + xRatios[x] * frame[yNextIndex + xIndex + 1]);
        drawPixel(319 - x, y, val);
      }
    }
  }

  else if (interpolationMode == 4) {
    for (int y = 0; y < 240; y++) {
      int yIndex = (y / 10) * 32;
      int yNextIndex = ((y / 10) + 1) * 32;  // Next row in original data
      for (int x = 0; x < 320; x++) {
        int xIndex = x / 10;

        // Determine which triangle the point is in and interpolate accordingly
        float t = (x % 10) / 10.0f;  // Horizontal distance from left pixel center
        float u = (y % 10) / 10.0f;  // Vertical distance from top pixel center
        float val;
        if (t > u) {  // Point is in lower-left triangle
          // Interpolate between bottom-left, top-right, and bottom-right
          val = (1 - t) * frame[yNextIndex + xIndex] + (1 - u) * frame[yIndex + xIndex + 1] + (t + u - 1) * frame[yNextIndex + xIndex + 1];
        } else {  // Point is in upper-right triangle
          // Interpolate between top-left, bottom-right, and top-right
          val = (1 - t) * frame[yIndex + xIndex] + (1 - u) * frame[yNextIndex + xIndex + 1] + (t + u - 1) * frame[yIndex + xIndex + 1];
        }

        drawPixel(319 - x, y, val);
      }
    }
  }



  // Display the maximum, minimum and center temperatures as overlay
  sprite.setTextColor(TFT_BLACK);
  sprite.setTextSize(1);

  sprite.setFreeFont(&Open_Sans_ExtraBold_10);

  sprite.drawString("T Min: " + String(tempMinRead) + " C", 15, 220);
  sprite.drawString("T Max: " + String(tempMaxRead) + " C", 220, 220);
  sprite.drawString("Tc: " + String(tempCenter, 1) + "C", 135, 220);
  // Display a small crosshair at the center
  sprite.drawLine(155, 120, 165, 120, TFT_WHITE);
  sprite.drawLine(160, 115, 160, 125, TFT_WHITE);

  detachInterrupt(digitalPinToInterrupt(downButton));
  batv = ((float)analogRead(VBAT_PIN) / 4095) * 2 * 1.07 * 3.3;
  attachInterrupt(digitalPinToInterrupt(downButton), downButton_ISR, CHANGE);
  int batpc = (uint8_t)(((batv - BATTV_MIN) / (BATTV_MAX - BATTV_MIN)) * 100);
  drawBattery(batpc);
  if (Menu == 1) {
    MenuChange = false;
    sprite.fillRect(60, 40, 200, 120, TFT_BLACK);
    sprite.fillRect(60, 40, 200, 10, TFT_WHITE);
    sprite.setTextFont(0);
    sprite.setTextSize(1);
    sprite.setTextColor(TFT_BLACK);
    sprite.drawString("Settings", 140, 41);
    sprite.setTextColor(TFT_WHITE);
    for (int i = 0; i < 7; i++) {
      if (i == Menuitem) sprite.setTextColor(TFT_GREEN);
      int y = 55 + (15 * i);
      sprite.drawString(menuItems[i], 65, y);
      if (i == 0) {
        sprite.drawString(ASindex[AutoScale], 160, y);
      } else if (i == 1) {
        sprite.drawString(String(MinT) + " C", 160, y);
      } else if (i == 2) {
        sprite.drawString(String(MaxT) + " C", 160, y);
      } else if (i == 3) {
        sprite.drawString(IPindex[interpolationMode], 160, y);
      } else if (i == 4) {
        sprite.drawString("Palette " + String(paletteIndex), 160, y);
      } else if (i == 5) {
        sprite.drawString(RRindex[RefreshRate], 160, y);
      } else if (i == 6) {
        sprite.drawString(String(BLPWM) + " %", 160, y);
      }
      sprite.setTextColor(TFT_WHITE);
    }
  }
  sprite.pushSprite(0, 0);
}

void drawPixel(int x, int y, float val) {
  int colorIndex;
  if (AutoScale == 1) {
    if (val <= tempMin) {
      colorIndex = 0;
    } else if (val >= tempMax) {
      colorIndex = 5;
    } else {
      // Map the value to a color index between 0 and 5
      colorIndex = int(map(val, tempMin, tempMax, 0, 5));
    }
  } else {
    if (val <= MinT) {
      colorIndex = 0;
    } else if (val >= MaxT) {
      colorIndex = 5;
    } else {
      // Map the value to a color index between 0 and 5
      colorIndex = int(map(val, MinT, MaxT, 0, 5));
    }
  }
  int color = colorPalettes[paletteIndex][colorIndex];
  sprite.drawPixel(x, y, color);
}
void drawBattery(int batpc) {
  int x = 290;
  int y = 10;
  int w = 20;
  int h = 10;
  int color = TFT_RED;  // Default color for the lowest level


  // Determine fill level and color based on batpc
  int fillLevel = 0;
  if (batpc > 75) {
    fillLevel = w;  // 100%
    color = TFT_GREEN;
  } else if (batpc > 50) {
    fillLevel = w * 3 / 4;  // 75%
    color = TFT_GREEN;
  } else if (batpc > 25) {
    fillLevel = w / 2;  // 50%
    color = TFT_BLUE;
  } else if (batpc > 0) {
    fillLevel = w / 4;  // 25%
    color = TFT_BLUE;
  }


  // Draw battery outline
  sprite.drawRect(x, y, w, h, TFT_WHITE);
  sprite.drawRect(x + w, y + h / 4, 2, h / 2, TFT_WHITE);
  // Draw fill level
  if (fillLevel > 0) {
    sprite.fillRect(x + 1, y + 1, fillLevel - 2, h - 2, color);
  }
}
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
void loop() {
  navigationUpdate();
  displayUpdate();
}

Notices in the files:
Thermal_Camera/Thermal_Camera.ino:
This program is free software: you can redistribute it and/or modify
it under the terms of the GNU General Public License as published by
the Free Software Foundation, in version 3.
